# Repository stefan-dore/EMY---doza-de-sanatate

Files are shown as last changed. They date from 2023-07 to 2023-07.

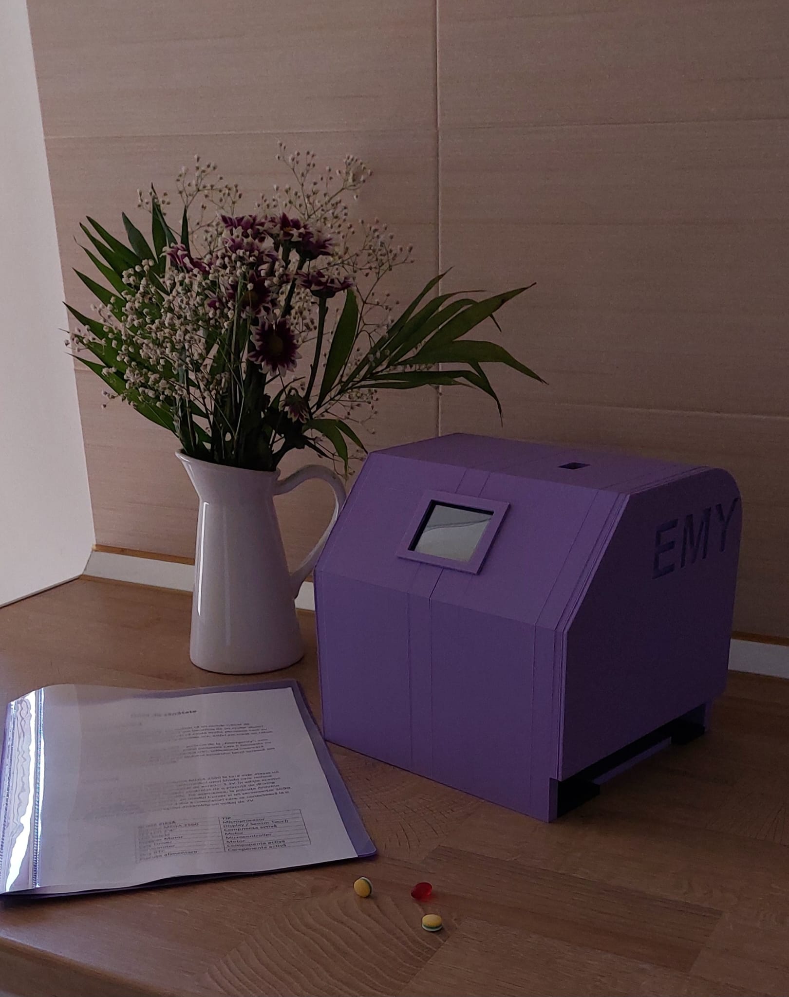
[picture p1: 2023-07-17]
Imagini/EMY_2.jpg

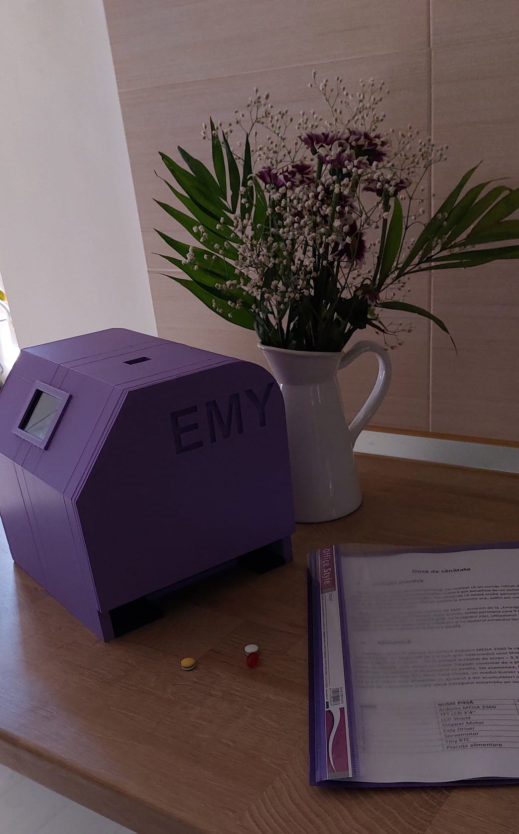
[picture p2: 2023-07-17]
Imagini/EMY_3.jpg

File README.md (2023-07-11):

# EMY

EMY este un dispenser de pastile ușor de folosit pentru oamenii de toate vârstele. Robotul are o utilizare multiplă, acesta putând fi folosit atât în reședințe personale, spitale, centre pentru seniori și centre pentru persoane cu nevoi speciale. Cu puține modificări, EMY poate fi folosit și ca prototip pentru dozatoare de mâncare pentru animalele de companie, cât și pentru adăposturile de animale.

# Autori

- Ștefan Dore : Software(programare), Hardware(mecanică, electronică)
- Teodora Matei : CAD(proiectare, design, printare), Hardware(mecanică)

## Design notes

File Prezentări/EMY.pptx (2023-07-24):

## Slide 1

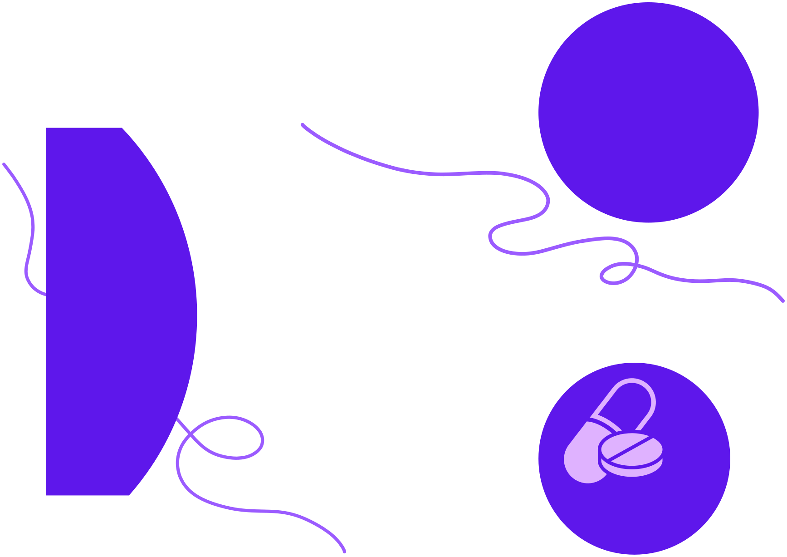
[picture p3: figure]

E

M

Y

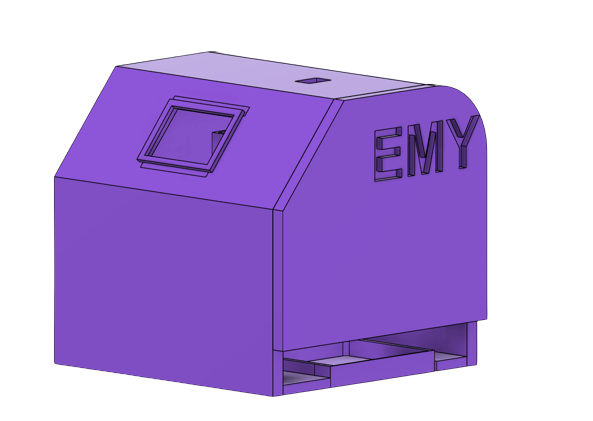
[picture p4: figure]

Dore Ștefan Cristian
Matei Andreea Teodora
Colegiul Național ,,Zinca Golescu ” Profesori coordonatori : Popa Gabriela
Luță Daniela

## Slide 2

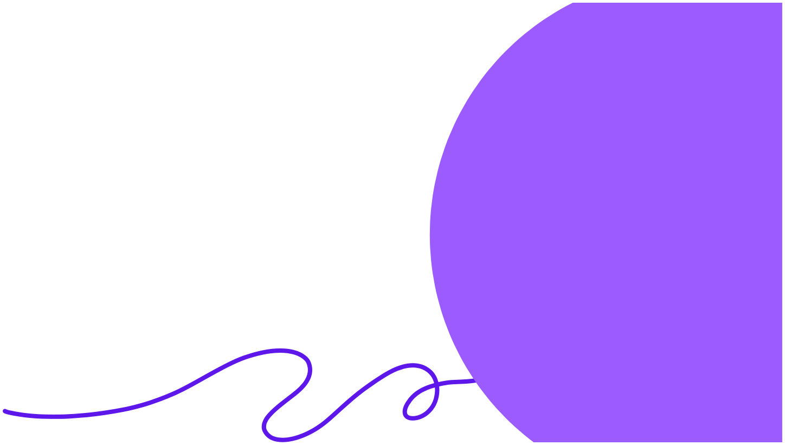
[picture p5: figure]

În urma unei sesiuni de brainstorming, am realizat că unii oameni ar putea beneficia de ajutor suplimentar când vine vorba de administrarea medicamentelor.
Astfel am găsit o soluție simplă și eficienta - EMY!

Misiunea lui EMY

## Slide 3

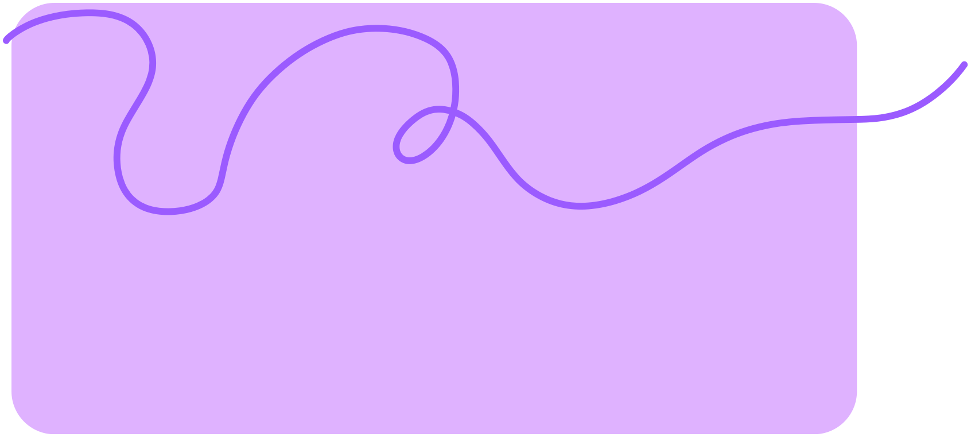
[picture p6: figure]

Întrebuințările lui EMY

în reședințe proprii

UTILIZARE

în centrele pentru seniori

in centrele pentru persoane cu dizabilități

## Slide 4

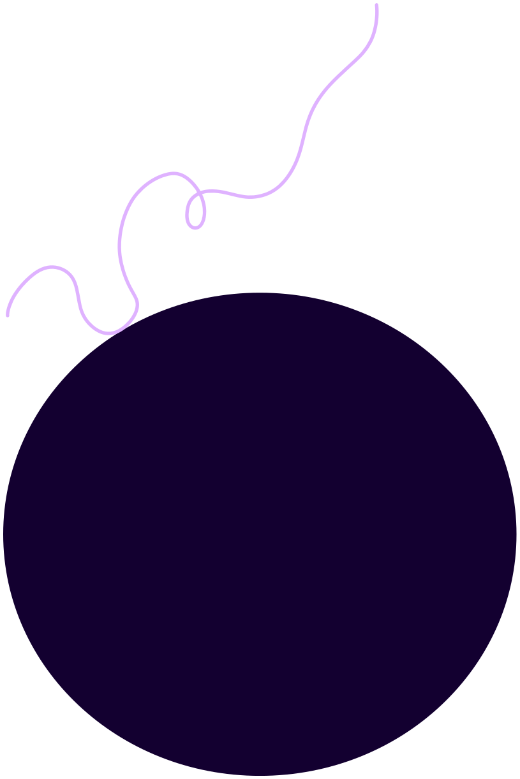
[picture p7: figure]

Procesul de creație

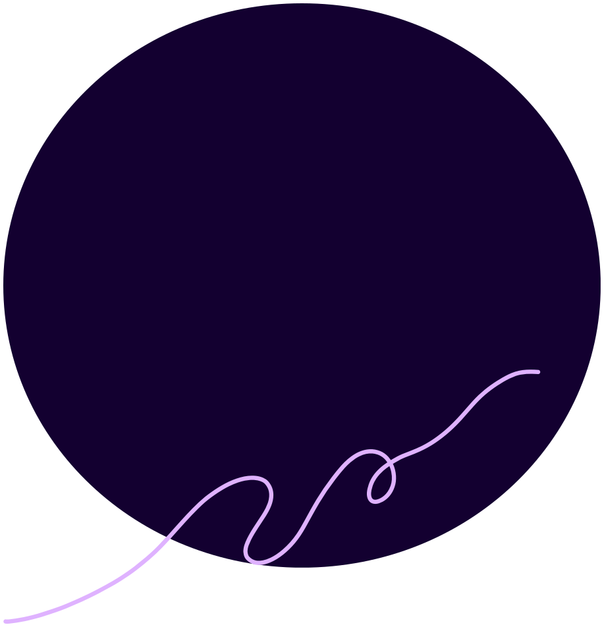
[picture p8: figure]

FINALIZARE PROTOTIP

PROGRAMARE

PROIECTARE 3D

ANSAMBLARE

PRINTAREA PIESELOR

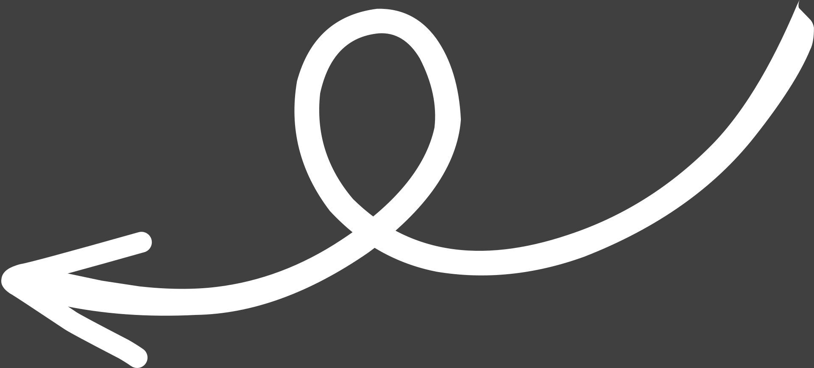
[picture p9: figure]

FINISARE

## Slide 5

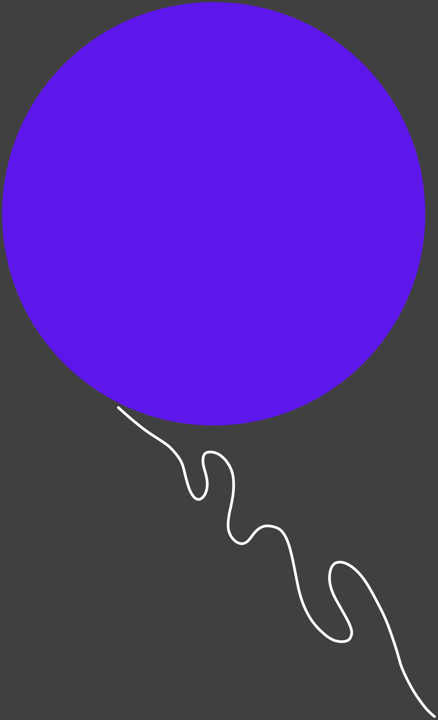
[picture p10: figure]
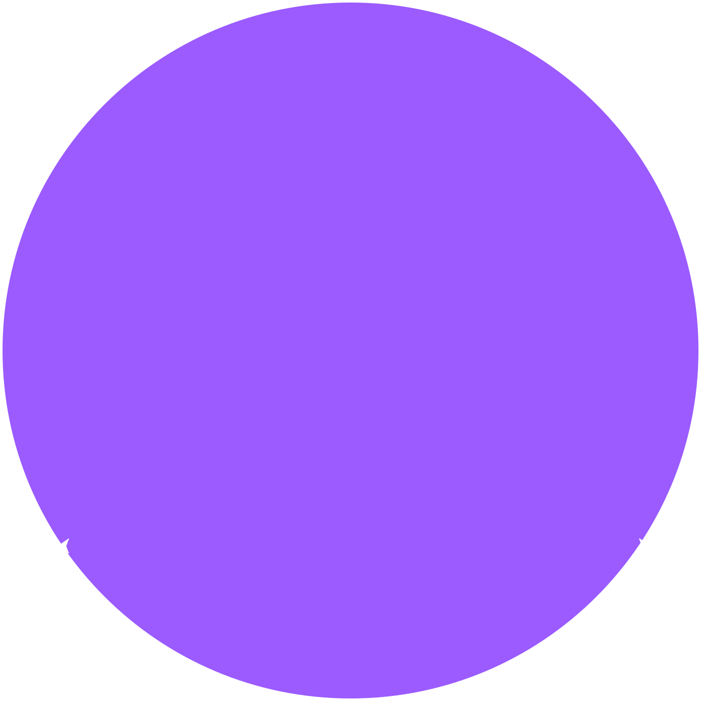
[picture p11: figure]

Unul dintre cei mai importanți pași din realizarea lui EMY, proiectarea 3D, a avut rolul in a optimiza cât mai mult posibil robotul. Cu ajutorul unui program CAD (Fusion 360), am realizat mai multe prototipuri pentru diferitele piese care il alcatuiesc pe EMY.

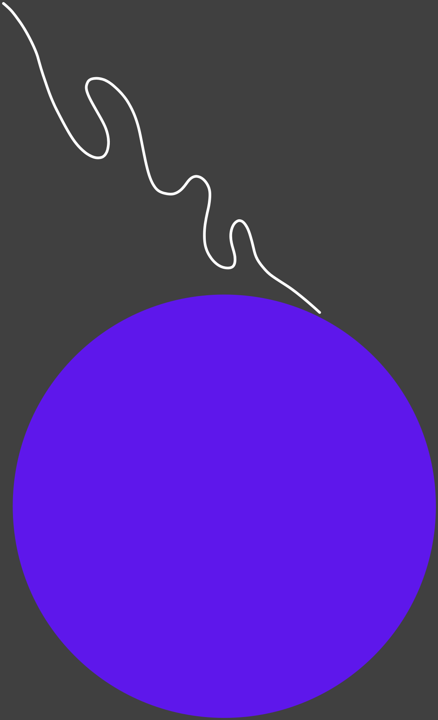
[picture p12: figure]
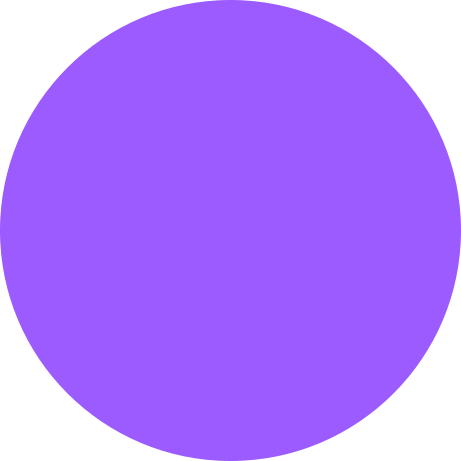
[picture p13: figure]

PROIECTARE 3D

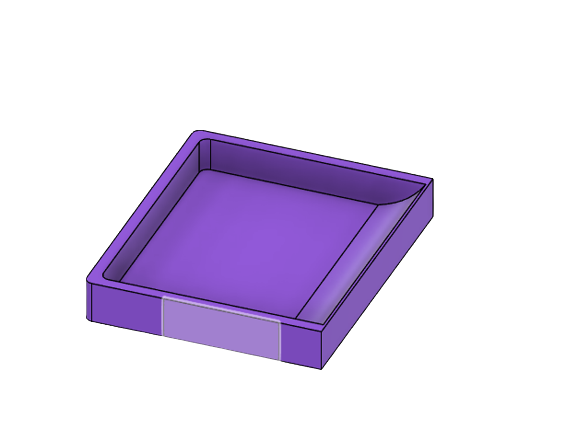
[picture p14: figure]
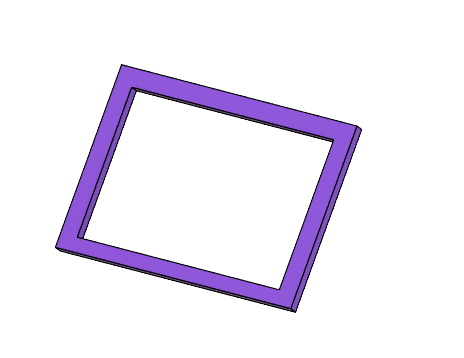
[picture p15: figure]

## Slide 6

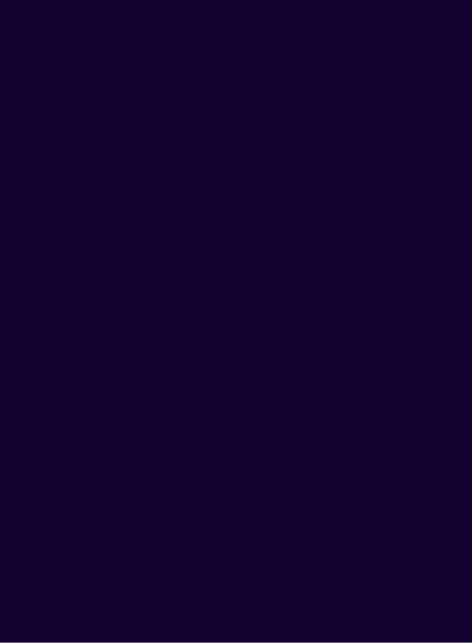
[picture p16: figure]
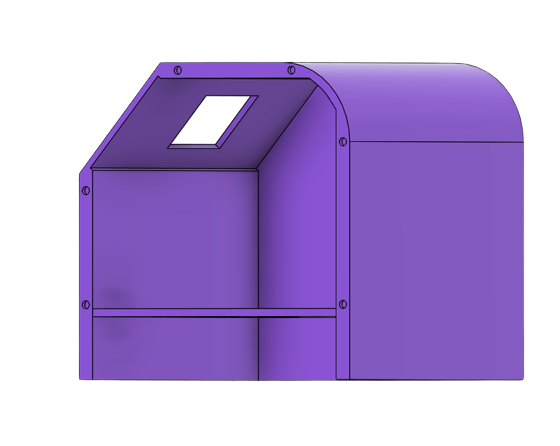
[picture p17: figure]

PRINTAREA PIESELOR

Pentru printarea pieselor a fost folosit filament de culoare mov de tip PLA. Procesul de printare a durat in jur de 100 de ore incluzând toate piesele din componența robotului atât cele interioare cât și cele exterioare.

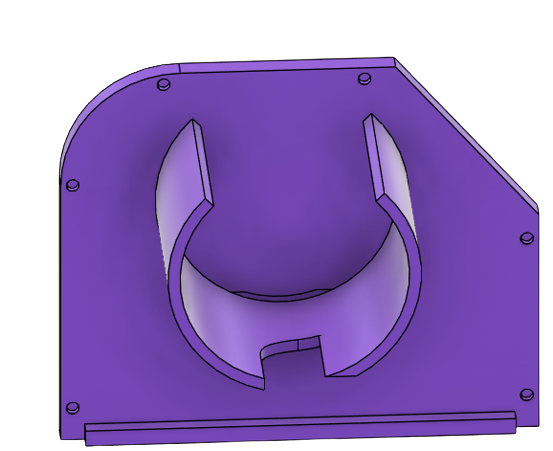
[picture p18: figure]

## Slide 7

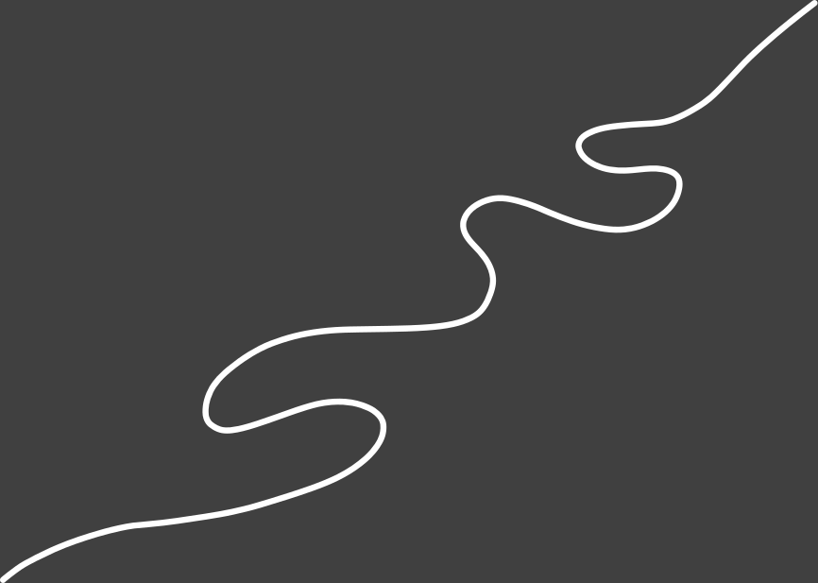
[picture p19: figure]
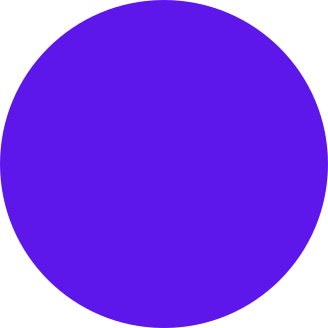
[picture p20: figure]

PIESE UTILIZATE

TFT LCD 2'4"

LCD Shield

Stepper Motor

Arduino MEGA 2560

Easy Driver

Servomotor

Tiny RTC

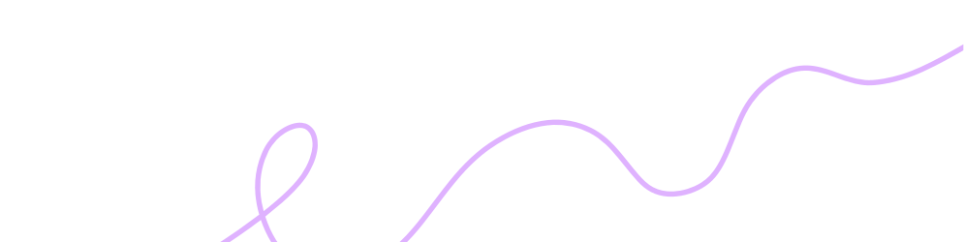
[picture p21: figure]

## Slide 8

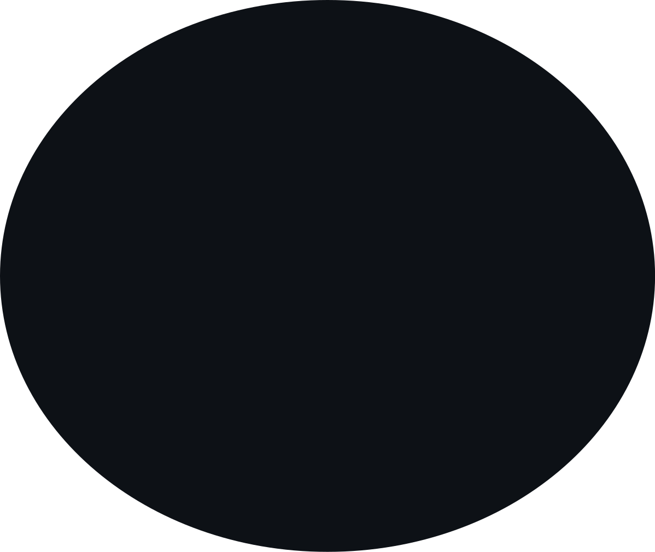
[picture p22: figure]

// Calcularea timpului rămas până la o anumită pastilă folosind ora reținută de RTC

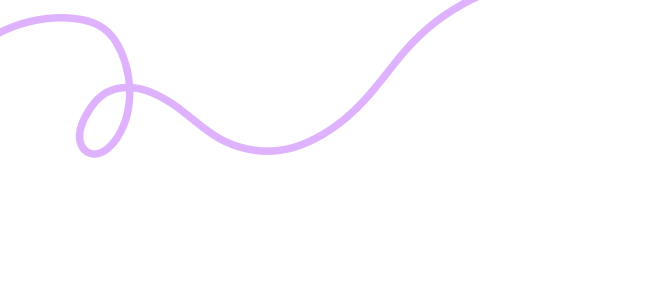
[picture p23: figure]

Codul sursă al lui EMY are o structură iterativă și folosește structuri repetitive doar acolo unde sunt necesare pentru a reduce timpul alocat executării programului din loop() și pentru a diminua spațiul ocupat in stivă cât mai mult posibil

PROGRAMARE

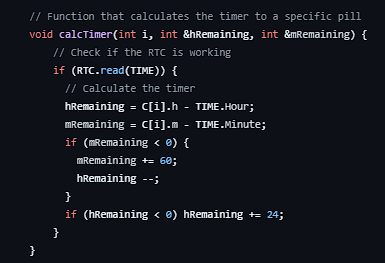
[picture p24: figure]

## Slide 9

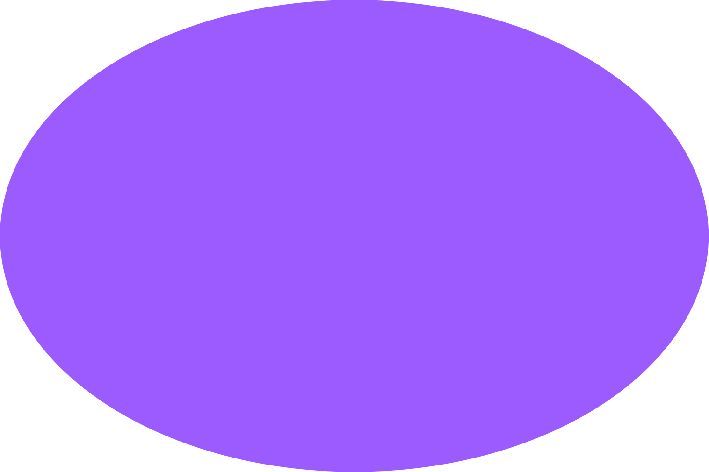
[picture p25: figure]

Alte utilizari

Robotul realizat de noi poate funcționa, de asemenea, și ca un prototip pentru dozatoarele de mâncare atât pentru animalele de companie cât și pentru adăposturile de animale

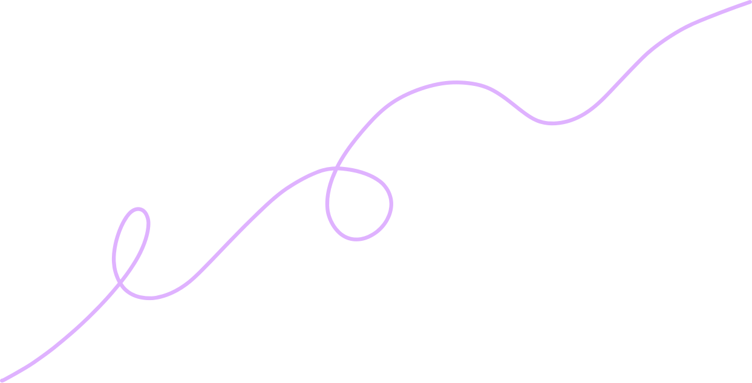
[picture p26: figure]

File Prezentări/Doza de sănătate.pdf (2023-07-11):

## Doza de sănătate

## I. Utilitate practică

În urma unei sesiuni de brainstorming, am realizat că un număr ridicat de persoane care fac parte din comunitatea noastră pot beneficia de un ajutor atunci când vine vorba de medicamentație. Am observat că există multe persoane care au nevoie de administrarea unor diferite pastile la anumite ore, astfel am creat un robot care îmbunătățește procesul.

Robotul nostru, care poartă numele de EMY – acronim de la „Emergency”, este gândit pentru a ușura și eficientiza acest proces, astfel persoana care îl folosește nu mai este nevoită să stea cu această grijă. La începutul zilei, utilizatorul inserează pastilele prin partea superioară a robotului și cu ajutorul ecranului tactil setează ora individuală la care trebuie să ia fiecare pastilă.

## II. Mecanică

Robotul utilizează plăcuța de control Arduino MEGA 2560 la care este atașat un ecran LCD TFT cu diagonală de 2.4 inch prin intermediul unui Shield care reduce voltajul oferit de Arduino – 5V la voltajul acceptat de ecran – 3.3V. În adiția acestui ecran, la placuță, este atașat un motor Stepper controlat de o placuță de driving EasyDriver ce acționează dispenserul cu pastile. De asemenea, la plăcuța Arduino este conectat un Tiny RTC (Real Time Clock), un modul buzzer și un servomotor SG90. Tot acest sistem este alimentat cu ajutorul a doi acumulatori care se conectează la o placuță de alimentare și care oferă întregului ansamblu un voltaj de 7V.

INDEX | NUME PIESĂ | TIP
1. | Arduino MEGA 2560 | Microprocesor
2. | TFT LCD 2’4’’ | Display / Senzor Touch
3. | LCD Shield | Compnenta activă
4. | Stepper Motor | Motor
5. | Easy Driver | Microcontroller
6. | Servomotor | Motor
7. | Tiny RTC | Componenta activă
8. | Placuța alimentare | Componenta activă

## III. Electronică

Arduino MEGA 2560

Plăcuța Arduino MEGA 2560 are intregrat un microprocesor, dar scopul ei principal este acela de a se comporta ca un controller pentru toate componentele electrice din ansamblul ce formează robotul, astfel încât aceasta controlează ecranul LCD, motorul Stepper și servomotorul.

Ecran LCD TFT 2’4”

Ecranul LCD TFT permite atât afișarea unui text/imagine pe acesta cât și transmiterea datelor către Arduino, acesta fiind un ecran tactil. Am ales să folosim acest tip de ecran pentru a nu fi nevoiți să implementăm altfel de butoane, dar și pentru a face interfața robotului mult mai prietenoasă pentru utilizator.

Shield pentru ecran

Rolul Shield-ului este de a reduce voltajul pe care placuța Arduino îl oferă la 3.3V - numărul de volți acceptați de ecranul TFT, fără acest Shield ecranul s-ar fi ars.

Motor Stepper

Motorul Stepper sau „motor pas cu pas” funcționează pe baza a 2 faze care îi dau rotația astfel încât atunci când curentul trece printr-una dintre cele două faze motorul avansează cu un pas. Numărul total de pași pentru o revoluție completă a acestui model de motor este de 1600 de pași.

Placuța EasyDriver

Placuța EasyDriver este un microcontroller care se conectează la Arduino, la motor și la sursa de alimentare. Aceasta funcționează în următorul fel: atunci când primește un semnal de la Arduino, lasă curentul de la sursă să treacă alternant prin cele 2 faze astfel rotind motorul cu un pas.

Servomotorul

Pentru servomotor nu este nevoie de o plăcuța de driving, el poate funcționa conectat direct la Arduino prin intermediul a 3 cabluri (5V/VCC, GND, PWM). Astfel motorul se rotește atunci când primește un semnal de la cablul conectat la pinul de tip PWM.

Placuța de alimentare

Cum acumulatorul nu poate fi conectat direct la placuța EasyDriver, am folosit o placuță de alimentare pentru a adapta modul de transmitere al curentuleui, astfel acumulatorul este conectat la placuța de alimentare care la rândul ei este conectată la microcontrollerul EasyDriver.

Tiny RTC

Plăcuța Tiny RTC funcționează ca un ceas chiar și când plăcuța Arduino nu este alimentată deoarece este conectată la un acumulator separat. Astfel pe ecranul robotului este afișată ora exactă indiferent de cât de mult timp robotul a fost oprit.

## IV. Software

Robotul se folosește de diferite librarii, unele deja implementate în mediul de lucru Arduino IDE - Wire.h, Servo.h, altele importate manual de catre programator -UTFT.h, URTouch.h, DS1307RTC.h, TimeLib.h, pentru a putea acționa toate componentele și pentru ai permite să primească informații de la anumite componente cum ar fi ecranul sau RTC-ul.

În ceea ce privește autonomia robotului, acesta
nu are nevoie de niciun fel de asistență externă
pentru a funcționa înafară de interacțiunile utilizatorului cu el care constau în introducerea pastilei și setarea orei la care trebuie administrată.

Programul este construit eficient , acesta folosind structuri iterative în loc de cele recursive pentru a reduce cât mai mult posibil spațiul ocupat în stivă și timpul executării. În același timp, pentru a optimiza și mai mult timpul de rulare, structurile repetitive au fost folosite doar când erau necesare și au fost găsite alte metode de rezolvare a unei probleme acolo unde acest
tip de structuri păreau sa fie eficiente.

Scriptul este organizat pe module, astfel încât un


anumit proces al robotului poate fi modificat individual fără a risca ca modificarea să dăuneze altui proces. Pe lângă această structură modulară a codului, în fișierul sursă sunt prezente comentarii care explică fiecare funcție implementata de programator si rolul fiecarei variabile.

MAI MULTE DETALII PRINTRE CARE ȘI CODUL, CAD-UL, IMAGINI CU ROBOTUL SE GĂSESC AICI:

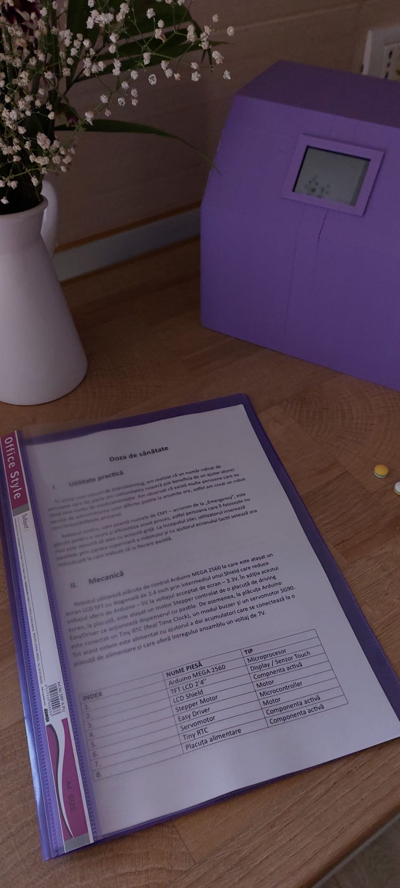
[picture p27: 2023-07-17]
Imagini/EMY_1.jpg

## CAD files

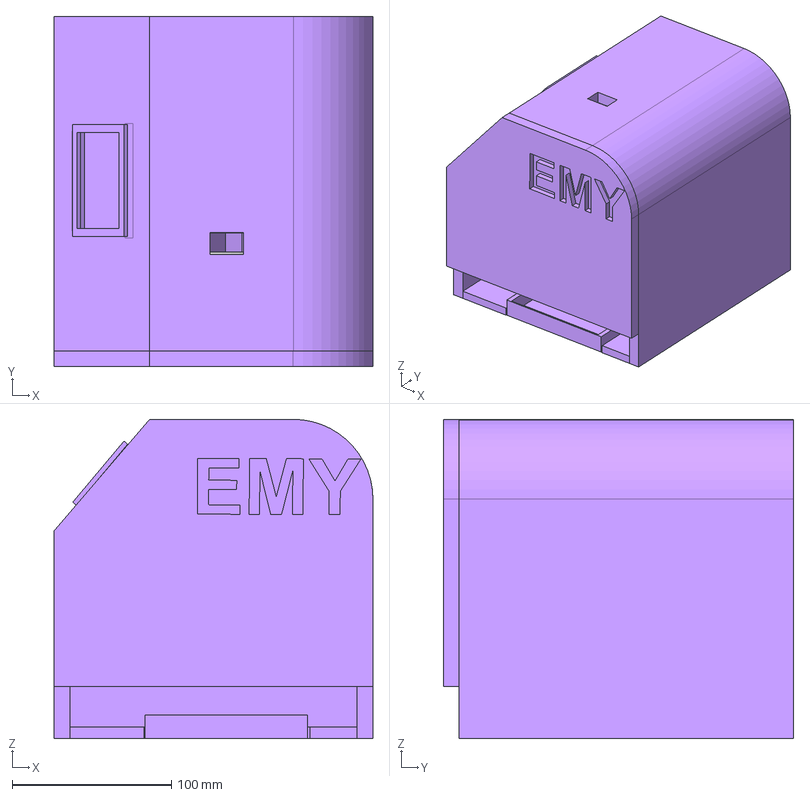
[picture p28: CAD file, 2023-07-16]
CAD/Emy.step
200.0 x 219.8 x 200.3 mm
usa nou
Dispenser
Suport motor
Prelungire servo
Suport stepper
Tavita colectare
Suport tavita
Cadru ecran

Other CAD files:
CAD/Emy.stl

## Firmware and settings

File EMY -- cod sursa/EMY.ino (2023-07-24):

// Include all nedeed libraries
#include <UTFT.h>
#include <URTouch.h>
#include <Wire.h>
#include <TimeLib.h>
#include <DS1307RTC.h>
#include <Servo.h>

// Define the 2 variables : step and direction for the stepper motor
#define DIRECTION 8 // assigned pin is PWM pin 8
#define STEP 9 // assigned pin is PWM pin 9 

// Initialize all the components
UTFT LCD(ILI9341_16, 38, 39, 40, 41);
URTouch Touch(6, 5, 4, 3, 2);
Servo servoMotor;

// Create a data structer that stores the pozition of a compartiment, if it is filled or not and its release time 
struct compartiment {
  bool filled; // 1 -- FILLED / 0 -- EMPTY
  int poz; // pozition
  int h, m; // release time
};

// Declare an one dimensional array that stores all the data for the 12 compariments
compartiment C[12];

// Declare 2 variables for adjusting what appears on screen 5
int first = 0, last = 4;

// Declare the fonts for the TFT screen
extern uint8_t BigFont[];
extern uint8_t SmallFont[]; 

// Declare the months as a constant so they can be accessed by the index
const char *monthName[13] = { "NULL",
  "Jan", "Feb", "Mar", "Apr", "May", "Jun",
  "Jul", "Aug", "Sep", "Oct", "Nov", "Dec"
};

// Declare a variable to know which screen the LCD needs to print
int SCREEN = 1;

// Declare 2 variables to know the exact position where the LCD was pressed
int xT, yT;

// Declare a few variables for storing the wheel numbers
int prevH = 23, currH = 0, nextH = 1, prevM = 59, currM = 0, nextM = 1;

// Declare the data structure for the RTC (stores sec,min,h,d,mo,y)
tmElements_t TIME;

// The motors steps (1600) do not divide exactly to the number of compartiments (12) so we  will use an adjustment (133*12+4 = 1600)
int adjustment = 1;

//----------------------//
//-- Custom functions --//
//----------------------//

// Function that adjust the format of the time if the value is one digit (BigFont)
void print2digitsB(int value, int x, int y) {
  if (value < 10) {
    LCD.printNumI(0, x, y);
    LCD.printNumI(value, x+15, y);  
  } else {
    LCD.printNumI(value, x, y);
  }
}

// Function that adjust the format of the time if the value is one digit (SmallFont)
void print2digitsS(int value, int x, int y) {
  if (value < 10) {
    LCD.printNumI(0, x, y);
    LCD.printNumI(value, x+7, y);  
  } else {
    LCD.printNumI(value, x, y);
  }
}

// Function that prepares the LCD for display
void prepLCD(int br, int bg, int bb, int cr, int cg, int cb, char fontSize[] ) {
  LCD.setBackColor(br, bg, bb);
  LCD.setColor(cr, cg, cb);
  if (strcmp(fontSize, "BigFont") == 0) { 
    LCD.setFont(BigFont);
  } else if (strcmp(fontSize, "SmallFont") == 0) { 
    LCD.setFont(SmallFont);
  }
}

// Function that tells if a button was pressed 
bool buttonPressed(int xc, int yc, int xst, int yst, int xdr, int ydr) {
  return (xc >= xst && xc <= xdr && yc >= yst && yc <= ydr); 
}

// Function that prints the time and date
void printTimeDate() {
  // Prepare the LCD for the date & time
  prepLCD(0, 0, 0, 255, 255, 255, "BigFont");
  
  // Check if the RTC is working
  if (RTC.read(TIME)) {
    // Print the time
    print2digitsB(TIME.Hour, 110, 55);
    LCD.print(":", 150, 55);
    print2digitsB(TIME.Minute, 170, 55);

    // Print the date
    print2digitsB(TIME.Day, 70, 95);
    LCD.print(monthName[TIME.Month], 117, 95);
    LCD.printNumI(tmYearToCalendar(TIME.Year), 180, 95);
  }
}

// Functions that prints UP-ARROW
void printUP_ARROW(int x, int y) {
  LCD.fillRect(x, y, x+30, y-2); // 65 90
  LCD.fillRect(x+2, y-2, x+28, y-4);
  LCD.fillRect(x+4, y-4, x+26, y-6);
  LCD.fillRect(x+6, y-6, x+24, y-8);
  LCD.fillRect(x+8, y-8, x+22, y-10);
  LCD.fillRect(x+10, y-10, x+20, y-12);
  LCD.fillRect(x+12, y-12, x+18, y-14);
  LCD.fillRect(x+14, y-14, x+16, y-16);  
}

// Functions that prints DOWN-ARROW
void printDOWN_ARROW(int x, int y) {
  LCD.fillRect(x, y-14, x+30, y-16); 
  LCD.fillRect(x+2, y-12, x+28, y-14);
  LCD.fillRect(x+4, y-10, x+26, y-12);
  LCD.fillRect(x+6, y-8, x+24, y-10);
  LCD.fillRect(x+8, y-6, x+22, y-8);
  LCD.fillRect(x+10, y-4, x+20, y-6);
  LCD.fillRect(x+12, y-2, x+18, y-4);
  LCD.fillRect(x+14, y, x+16, y-2);  
}

// Function that prints BACK-ARROW
void printBACK_ARROW() {
  LCD.fillRect(5, 10, 7, 12);
  LCD.fillRect(7, 8, 14, 14);
  LCD.fillRect(11, 6, 15, 16);
  LCD.fillRect(15, 4, 19, 18);
  LCD.fillRect(19, 2, 23, 20);
  LCD.fillRect(23, 6, 43, 16);
  LCD.fillRect(35, 8, 45, 28);
  LCD.fillRect(37, 28, 43, 30);
}

// Functions that prints the numbers wheel
void printNumbWheel() {
  prepLCD(0, 0, 0, 255, 255, 255, "BigFont");
  print2digitsB(currH, 107, 105);
  print2digitsB(currM, 187, 105);
  prepLCD(0, 0, 0, 255, 255, 255, "SmallFont");
  print2digitsS(prevH, 118, 80);
  print2digitsS(nextH, 118, 135);
  print2digitsS(prevM, 198, 80);
  print2digitsS(nextM, 198, 135);
}

// Function that updates the number wheel
void updateNumbWheel(int xT, int yT) {
  // Hour section
  if (buttonPressed(xT, yT, 65, 80, 95, 94)) {
    if (prevH == 23) prevH = 0;
    else prevH++;
    if (currH == 23) currH = 0;
    else currH++;
    if (nextH == 23) nextH = 0;
    else nextH++;
  }
  if (buttonPressed(xT, yT, 65, 121, 95, 135)) {
    if (prevH == 0) prevH = 23;
    else prevH--;
    if (currH == 0) currH = 23;
    else currH--;
    if (nextH == 0) nextH = 23;
    else nextH--;
  }
  // Minute section
  if (buttonPressed(xT, yT, 230, 80, 260, 94)) {
    if (prevM == 59) prevM = 0;
    else prevM++;
    if (currM == 59) currM = 0;
    else currM++;
    if (nextM == 59) nextM = 0;
    else nextM++;
  }
  if (buttonPressed(xT, yT, 230, 121, 260, 135)) {
    if (prevM == 0) prevM = 59;
    else prevM--;
    if (currM == 0) currM = 59;
    else currM--;
    if (nextM == 0) nextM = 59;
    else nextM--;
  }
  delay(200);
}

// Function that searches for a empty compartiment
int emptyComp () {
  for (int i = 0; i < 12; i++)
    if (C[i].filled == 0)
      return i;
  return -1; 
}

// Function that adds data to the array and resets the variables for the number wheel
void addPill(int H, int M, int poz) {
   C[poz].h = H;
   C[poz].m = M;
   C[poz].filled = 1;
   prevH = 23; currH = 0; nextH = 1; prevM = 59; currM = 0; nextM = 1;
}

// Function that compares two compartiment type variables
int comp(compartiment a, compartiment b) {
  if (a.h > b.h) {
    return 1;
  } if (a.h == b.h) {
    if (a.m > b.m) {
      return 1;
    } else if (a.m < b.m){
      return 0;
    } else return 1;
  } else return 0;
}

// Function that swaps 2 elements int the compartiment array
void swapC(int poz1, int poz2) {
   int aux1 = C[poz1].h, aux2 = C[poz1].m, aux3 = C[poz1].poz, aux4 = C[poz1].filled;
   C[poz1].h = C[poz2].h; C[poz1].m = C[poz2].m; C[poz1].poz = C[poz2].poz; C[poz1].filled = C[poz2].filled;
   C[poz2].h = aux1; C[poz2].m = aux2; C[poz2].poz = aux3; C[poz2].filled = aux4;
}

// Function that sorts the elements of an array in descending order
void sort(compartiment arr[], int lenght) {
  int i, j;
  bool swapped;
  do{
    swapped = false;
    for (i = 0; i < lenght-1; i++) {
      if (comp(C[i], C[i+1]) == 0) {
        swapC(i, i+1);
        swapped = true;
      }
    }
  } while (swapped == true);
}

// Function that prints the timer text
void printTimerText(int pozY, int i) {
  LCD.print("MED ", 20, pozY);
  LCD.printNumI(i, 80, pozY);
  if (i > 9)
    LCD.print(".", 110, pozY);
  else
    LCD.print(". ", 93, pozY);
}

// Function that calculates the timer to a specific pill
void calcTimer(int i, int &hRemaining, int &mRemaining) {
    // Check if the RTC is working
    if (RTC.read(TIME)) {
      // Calculate the timer
      hRemaining = C[i].h - TIME.Hour;
      mRemaining = C[i].m - TIME.Minute;
      if (mRemaining < 0) {
        mRemaining += 60;
        hRemaining --;
      }
      if (hRemaining < 0) hRemaining += 24;
    }
}

// Function that prints the timer to a specific pill
void printTimer (int pozY, int i) {
  // Variables to store the timer data
  int mRemaining = 0, hRemaining = 0;
  if (C[i].filled == 1) {
      // Calculate the timer
      calcTimer(i, hRemaining, mRemaining);
      // Print the timer
      print2digitsB(hRemaining, 135, pozY);
      LCD.print(":", 165, pozY);
      print2digitsB(mRemaining, 180, pozY);
  } else LCD.print(" GOL  ", 130, pozY);
}

// Function that prints the schedule
void printSchedule (int first, int last) {
  int yPoz = 50;
  prepLCD(0, 0, 0, 255, 255, 255, "BigFont");
  for (first; first <= last; first++) {
    printTimerText(yPoz, first+1);
    printTimer(yPoz, first);
    yPoz += 40;
  }
}

// Function that updates the med wheel
void updateMedWheel() {
  if (buttonPressed(xT, yT, 260, 95, 290, 111) && first >= 1) {
    first--;
    last--;
  }
  if (buttonPressed(xT, yT, 260, 137, 290, 153) && last <= 10) { 
    first++;
    last++;
  }
}

// Function that rotates the motor
void rotateMotor(int numbOfComp) {
  for (int i = 1; i <= 133*numbOfComp + adjustment/3; i++) {
    digitalWrite(9, HIGH);
    delay(1);
    digitalWrite(9, LOW);
    adjustment++;
    if (adjustment > 3)
    adjustment = 1;
  }
  for (int i = 1; i <= numbOfComp; i ++) {
    for (int j = 0; j < 12; j++) {
      C[j].poz++;
      if (C[j].poz > 12)
        C[j].poz = 1;
    }
  }
}

// Function that checks for empty compartiments
bool checkForEmpty() {
  for (int i = 0; i < 12; i++) {
    if (C[i].filled == 0) {
      if (C[i].poz != 1)
        rotateMotor(13-C[i].poz);
      return 1;
    } 
  }
  return 0;
}

// Function that checks if one of the timers is 00.00 
void checkTimer() {
  for (int i = 0; i < 12; i++) {
    if (C[i].m == TIME.Minute && C[i].h == TIME.Hour && C[i].filled == 1) { 
      if (C[i].poz <= 7)
        rotateMotor(7-C[i].poz);
      else
        rotateMotor(19-C[i].poz);
    C[i].m = 0; C[i].h = 0; C[i].filled = 0;
    servoMotor.write(25);
    sort(C, 12);
    delay(5000);
    servoMotor.write(119);
    }
  }
}

// Function that draws screen 1 (HOME SCREEN)
void drawScreen1() {
  // Print the time and date
  printTimeDate();
  
  // Draw the button
  LCD.fillRect(40, 145, 279, 185);

  // Prepare the LCD for the text 
  prepLCD(255, 255, 255, 0, 0, 0, "BigFont");

  // Print the text
  LCD.print("MENIU", CENTER, 158);
}

// Function that draws screen 2 (MENU SCREEN)
void drawScreen2() {
  // Prepare the LCD for the buttons
  prepLCD(0, 0, 0, 255, 255, 255, "BigFont");

  // Print the retun arrow at the top left of the screen
  printBACK_ARROW();

  // Draw the buttons
  LCD.fillRect(40, 60, 279, 100);
  LCD.fillRect(40, 140, 279, 180);

  // Prepare the LCD for the text
  prepLCD(255, 255, 255, 0, 0, 0, "BigFont");

  // Print the text
  LCD.print("ADAUGA MED.", CENTER, 73);
  LCD.print("PROGRAM", CENTER, 153);
}

// Function that draws screen 3 (INSERTION SCREEN)
void drawScreen3() {
  // Prepare the LCD for the top text
  prepLCD(0, 0, 0, 255, 255, 255, "BigFont");

  // Print the top text
  LCD.print("INTRODUCE-TI MED.", CENTER, 55);
  LCD.print("IN ORIFICIU", CENTER, 75);
  
  // Prepare the LCD for the button
  prepLCD(0, 0, 0, 255, 255, 255, "BigFont");

  // Print the retun arrow at the top left of the screen
  printBACK_ARROW();

  // Draw the button
  LCD.fillRect(40, 130, 279, 170);

  // Prepare the LCD for the button text
  prepLCD(255, 255, 255, 0, 0, 0, "BigFont");

  // Print the button text
  LCD.print("GATA", CENTER, 143);
}

// Function that draws screen 4 (TIMER SCREEN)
void drawScreen4() {
  // Prepare the LCD for the top text
  prepLCD(0, 0, 0, 255, 255, 255, "BigFont");

  // Print the text
  LCD.print("SETATI ORA", CENTER, 20);
  LCD.print(":", 155, 105);

  // Print the numbers
  printNumbWheel();
  
  // Print the arrows
  printBACK_ARROW();
  printUP_ARROW(65, 90);
  printUP_ARROW(230, 90);
  printDOWN_ARROW(65, 152);
  printDOWN_ARROW(230, 152);

  // Draw the button
  LCD.fillRect(40, 190, 279, 230);

  // Prepare the LCD for the button text
  prepLCD(255, 255, 255, 0, 0, 0, "BigFont");

  // Print the button text
  LCD.print("GATA", CENTER, 203);
}

// Function that draws screen 5 (SCHEDULE SCREEN)
void drawScreen5() {
  prepLCD(0, 0, 0, 255, 255, 255, "BigFont");
  printBACK_ARROW();
  printSchedule(first, last);
  prepLCD(0, 0, 0, 0, 0, 0, "BigFont");
  LCD.fillRect(0, 230, 319, 240);
  prepLCD(0, 0, 0, 255, 255, 255, "BigFont");
  printUP_ARROW(260, 105);
  printDOWN_ARROW(260, 167);
}

// Function that tells the user the dispenser id full
void fullError() {
    // Prepare the LCD
    prepLCD(0, 0, 0, 255, 0, 0, "BigFont");
    LCD.clrScr();

    // Flash the message
    for (int i=1; i<=3; i++) {
      LCD.print("DISPENSER PLIN!", CENTER, 120);
      delay(700);
      LCD.clrScr();
      delay(100);
    }
}

void setup() {
  // Attach the servo to a pin and set it to the initial position
  servoMotor.attach(10);
  servoMotor.write(119);

  // Initialize the LCD and clear it and rotate it
  LCD.InitLCD();
  LCD.clrScr();

  // Initialize the Touch and set its precision
  Touch.InitTouch();
  Touch.setPrecision(PREC_MEDIUM);

  // Set the correct pinmode to the moor PWM pins
  pinMode(8, OUTPUT);
  pinMode(9, OUTPUT);

  // Set the rotation direction and reset the step pin
  digitalWrite(8, HIGH);
  digitalWrite(9, LOW);

  // Set the position for all the compartiments
  for (int i = 0; i < 12; i++)
    C[i].poz = i+1;
}

void loop() {
  // Print the coresponding screen
  switch (SCREEN) {
    case 1:
      drawScreen1();
      while (SCREEN == 1) {
        // Check if one of the pills needs to drop
        checkTimer();  
        // Update the date 
        printTimeDate();
        // Check if the button was pressed and if yes switch to screen 2
        if(Touch.dataAvailable()) {
          Touch.read();
          xT = 319 - Touch.getX();
          yT = 259 - Touch.getY();
          if (buttonPressed(xT, yT, 40, 130, 279, 155) == 1) {
           SCREEN = 2;
           LCD.clrScr();
           break;
          }
        }
      }
      break;
    case 2: 
      drawScreen2();
      while (SCREEN == 2) {
        // Check if one of the pills needs to drop
        checkTimer();  
        // Check if one of the buttons was pressed and if yes switch to the coresponding screen
        if(Touch.dataAvailable()) {
          Touch.read();
          xT = 319 - Touch.getX();
          yT = 259 - Touch.getY();
          if (buttonPressed(xT, yT, 40, 80, 279, 100)) {
           if (checkForEmpty()) {
            SCREEN = 3;
            LCD.clrScr();
            break;
           } else {
            fullError();
            SCREEN = 2;
            LCD.clrScr();
            break;
           }
          }
          if (buttonPressed(xT, yT, 40, 130, 279, 150)) {
           SCREEN = 5;
           LCD.clrScr();
           break;
          }
          if (buttonPressed(xT, yT, 5, 2, 45, 50)) {
            SCREEN = 1;
            LCD.clrScr();
            break;
          }
        }
      }
      break;
    case 3:
      drawScreen3();
      while (SCREEN == 3) {
        // Check if one of the pills needs to drop
        checkTimer();  
        // Check if the button was pressed and if yes switch to screen 4
        if(Touch.dataAvailable()) {
          Touch.read();
          xT = 319 - Touch.getX();
          yT = 259 - Touch.getY();
          if (buttonPressed(xT, yT, 40, 125, 279, 145)) {
           SCREEN = 4;
           LCD.clrScr();
           break;
          }
          if (buttonPressed(xT, yT, 5, 2, 45, 65)) {
            SCREEN = 2;
            LCD.clrScr();
            break;
          }
        }
      }
      break;
    case 4:
      drawScreen4();
      while (SCREEN == 4) {
        // Check if one of the pills needs to drop
        checkTimer();  
        // Print the number wheel
        printNumbWheel();
        // Check if the button was pressed and if yes switch to screen 2
        if (Touch.dataAvailable()) {
          Touch.read();
          xT = 319 - Touch.getX();
          yT = 259 - Touch.getY();
          // Update the number wheel
          updateNumbWheel(xT, yT);
          if (buttonPressed(xT, yT, 40, 155, 279, 180)) {
            addPill(currH, currM, emptyComp()); 
            sort(C, 12);
            SCREEN = 2;
            LCD.clrScr();
            break; 
          }
          if (buttonPressed(xT, yT, 5, 2, 45, 65)) {
            SCREEN = 3;
            LCD.clrScr();
            break;
          }
        }
      }
      break;
    case 5:
      drawScreen5();
      // Check if the button was pressed and if yes switch to screen 2
      if (Touch.dataAvailable()) {
        Touch.read();
        xT = 319 - Touch.getX();
        yT = 259 - Touch.getY();
        if (buttonPressed(xT, yT, 5, 2, 45, 65)) {
          SCREEN = 2;
          LCD.clrScr();
          break;
        }
        updateMedWheel();
      }
      // Check if one of the pills needs to drop
      checkTimer();        
      break;
  }
}
